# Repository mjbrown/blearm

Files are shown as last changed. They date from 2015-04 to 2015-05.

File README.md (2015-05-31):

# blearm
Open source hardware, firmware, and software for a Bluetooth Low Energy PiHAT.  This PiHAT was used to control a robot arm demonstration for Maker Faire MSP.

1. Firmware includes BGScript and XML files which define the embedded Bluetooth Low Energy device.  
2. Mechanical files include all 3d printed models used to construct the robot arm.  
3. Hardware files include schematics and layout eagle files for the circuit board.  
4. Software includes python scripts used in the development of the hardware.xml settings for PWM.
5. Android includes the modified Bluetooth LE Android application used to control the blearm.

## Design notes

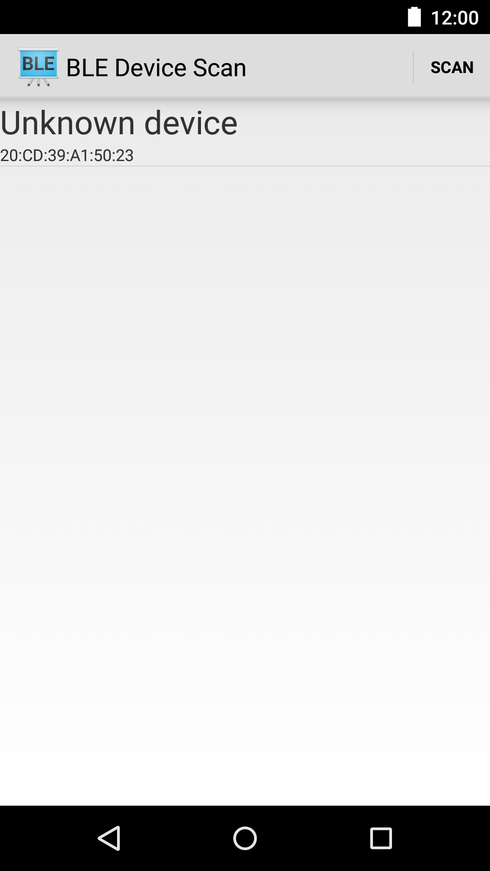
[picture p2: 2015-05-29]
android/screenshots/1-main.png

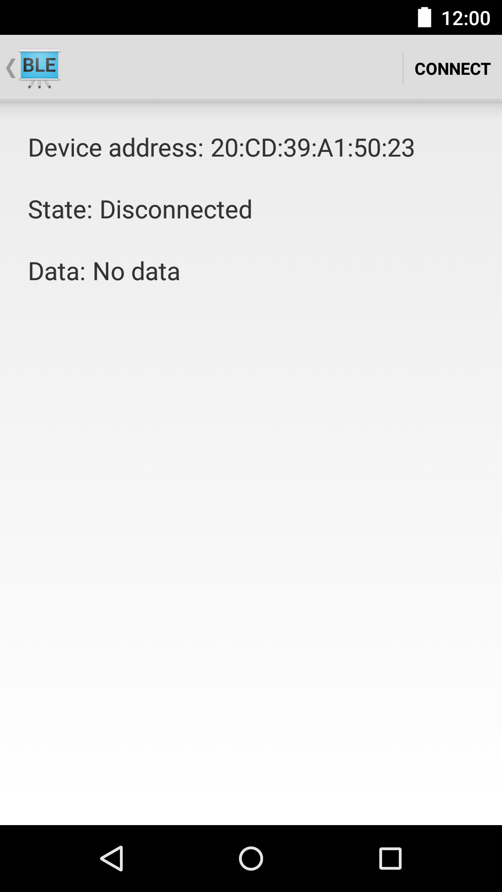
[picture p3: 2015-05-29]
android/screenshots/2-detail.png

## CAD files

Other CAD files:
mechanical/D-gear_wheel.skp
mechanical/D-gear_wheel_7mm.skp
mechanical/D-wheel.skp
mechanical/angle_join.skp
mechanical/arm_platform.skp
mechanical/axle_gear4.skp
mechanical/battery_clip.skp
mechanical/futaba_gear.skp
mechanical/gripper_arm.skp
mechanical/gripper_attach.skp
mechanical/gripper_base.skp
mechanical/gripper_left_claw.skp
mechanical/gripper_right_claw.skp
mechanical/gripper_servo_gear.skp
mechanical/gripper_slave_gear.skp
mechanical/midstop_gear.skp
mechanical/servo_arm.skp
mechanical/servo_arm_raspi.skp
mechanical/servo_horn_gear.skp
mechanical/servo_truck.skp
mechanical/servo_truck_opp.skp
mechanical/track_endstop.skp
mechanical/track_endstop_base.skp
mechanical/track_midstop.skp
mechanical/track_wheel.skp
mechanical/wire_clip.skp

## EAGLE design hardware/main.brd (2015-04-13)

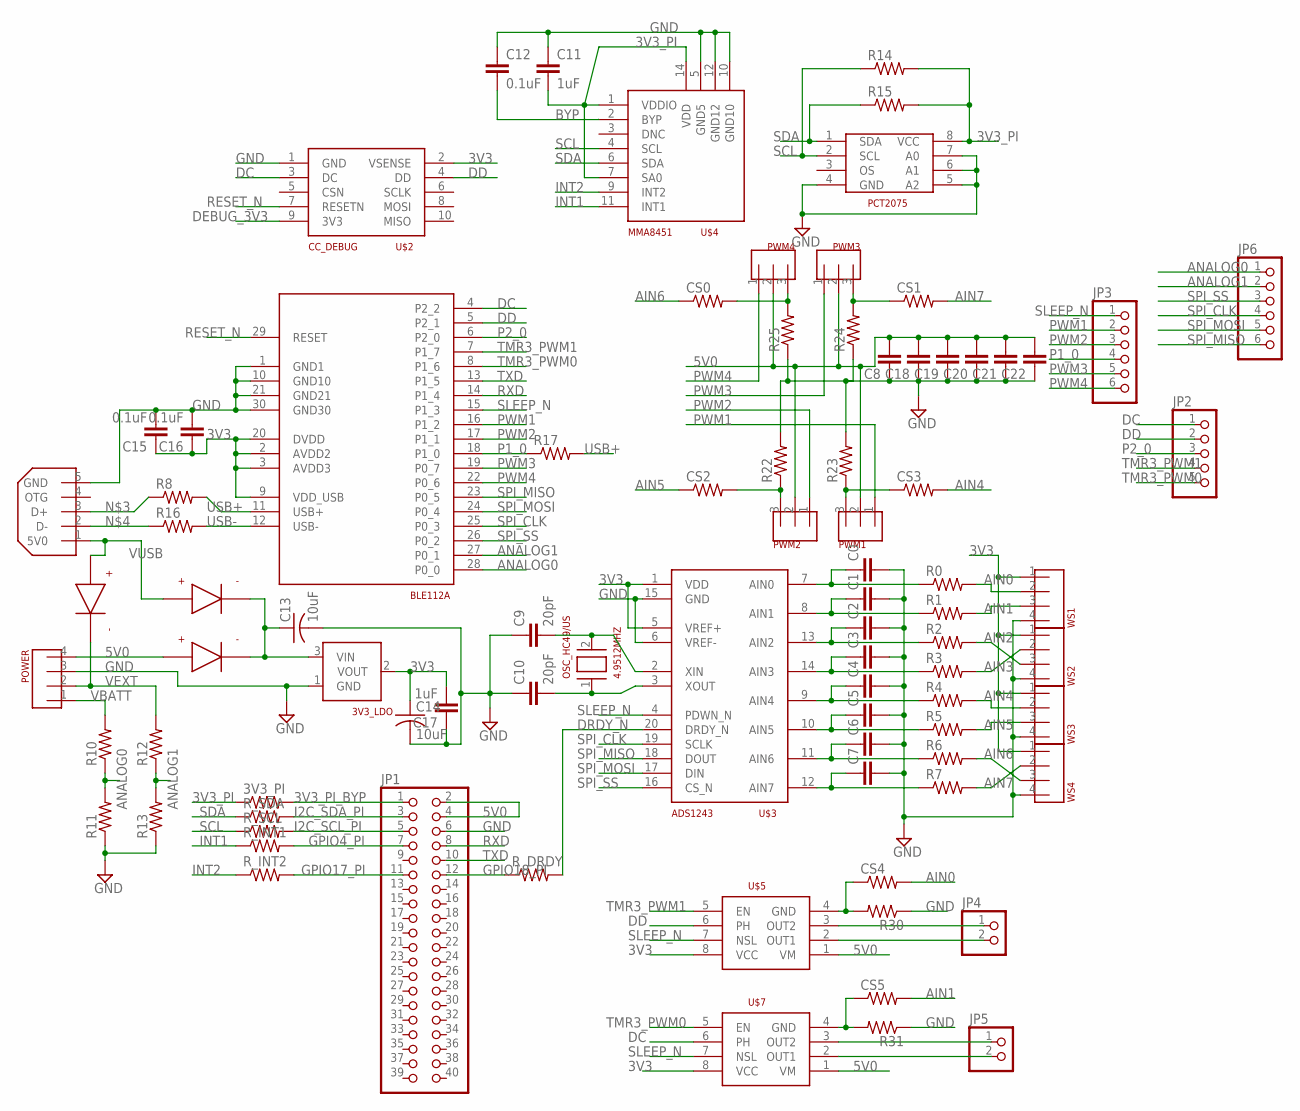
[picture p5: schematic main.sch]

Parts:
3V3_LDO: MCP1700; SOT23
3V3_PI: R-US_R0603; R0603
4.9512MHZ: OSC_HC49/US; HC49UP
BLE112A: BLE112A; BLE112
C0, C1, C2, C3, C4, C5, C6, C7, C8, C18, C19, C20, C21, C22: C-EUC0603; C0603
C9, C10: 20pF; C0603
C11, C17: 1uF; C0603
C12, C15, C16: 0.1uF; C0603
C13, C14: 10uF; C0805
CS0, CS1, CS2, CS3, CS4, CS5: R-US_R0603; R0603
JP1: PINHD-2X20; 2X20
JP2: PINHD-1X5; 1X05
JP3, JP6: PINHD-1X6; 1X06
JP4, JP5: PINHD-1X2; 1X02
PCT2075: PCT2075; SO-08
POWER: HDR_SPOX4
PWM1, PWM2, PWM3, PWM4: HDR_1X3
R0, R1, R2, R3, R4, R5, R6, R7, R8, R10, R11, R12, R13, R14, R15, R16, R17: R-US_R0603; R0603
R22, R23, R24, R25, R30, R31: R-US_R1206; R1206
R_DRDY: R-US_R0603; R0603
R_INT1, R_INT2: R-US_R0603; R0603
R_SCL: R-US_R0603; R0603
R_SDA: R-US_R0603; R0603
U$1, U$11, U$12: SCHOTTKEY_DIODE_1206; DIODE_1206
U$2: CC_DEBUG; HDR_2X5_127MM
U$3: ADS1243; TSSOP20
U$4: MMA8451; QFN16_3X3
U$5, U$7: DRV8838; WSON-8-PAD
U$6: MICRO_USB
WS1, WS2, WS3, WS4: HDR_1X4

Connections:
3V3: 3V3_LDO.2 (VOUT), BLE112A.2 (AVDD2), BLE112A.3 (AVDD3), BLE112A.9 (VDD_USB), BLE112A.20 (DVDD), C14.1, C15.1, C16.1, C17.2, U$2.2 (VSENSE), U$3.1 (VDD), U$3.5 (VREF+), U$5.8 (VCC), U$7.8 (VCC), WS1.1, WS2.1, WS3.1, WS4.1
3V3_PI: 3V3_PI.1, C11.2, PCT2075.8 (VCC), R14.2, R15.2, U$4.1 (VDDIO), U$4.7 (SA0), U$4.14 (VDD)
3V3_PI_BYP: 3V3_PI.2, JP1.1
5V0: C8.2, C18.2, C19.2, C20.2, C21.2, C22.2, JP1.2, JP1.4, POWER.4, PWM1.2, PWM2.2, PWM3.2, PWM4.2, U$5.1 (VM), U$7.1 (VM), U$12.CATHODE+
AIN0: CS4.2, R0.2, WS1.2
AIN1: CS5.2, R1.2, WS1.3
AIN2: R2.2, WS2.3
AIN3: R3.2, WS2.2
AIN4: CS3.2, R4.2, WS3.2
AIN5: CS2.1, R5.2, WS3.3
AIN6: CS0.1, R6.2, WS4.3
AIN7: CS1.2, R7.2, WS4.2
ANALOG0: BLE112A.28 (P0_0), JP6.1, R10.1, R11.2
ANALOG1: BLE112A.27 (P0_1), JP6.2, R12.1, R13.2
BYP: C12.2, U$4.2 (BYP)
DC: BLE112A.4 (P2_2), JP2.1, U$2.3 (DC), U$7.6 (PH)
DD: BLE112A.5 (P2_1), JP2.2, U$2.4 (DD), U$5.6 (PH)
DEBUG_3V3: U$2.9 (3V3)
DRDY_N: R_DRDY.2, U$3.20 (DRDY_N)
GND: 3V3_LDO.1 (GND), BLE112A.1 (GND1), BLE112A.10 (GND10), BLE112A.21 (GND21), BLE112A.30 (GND30), C0.2, C1.2, C2.2, C3.2, C4.2, C5.2, C6.2, C7.2, C8.1, C9.1, C10.1, C11.1, C12.1, C13.2, C14.2, C15.2, C16.2, C17.1, C18.1, C19.1, C20.1, C21.1, C22.1, JP1.6, PCT2075.4 (GND), PCT2075.5 (A2), PCT2075.6 (A1), PCT2075.7 (A0), POWER.3, R11.1, R13.1, R22.2, R23.2, R24.1, R25.1, R30.1, R31.1, U$2.1 (GND), U$3.6 (VREF-), U$3.15 (GND), U$4.5 (GND5), U$4.10 (GND10), U$4.12 (GND12), U$6.5 (GND), WS1.4, WS2.4, WS3.4, WS4.4
GPIO4_PI: JP1.7, R_INT1.2
GPIO17_PI: JP1.11, R_INT2.2
GPIO18_PI: JP1.12, R_DRDY.1
I2C_SCL_PI: JP1.5, R_SCL.2
I2C_SDA_PI: JP1.3, R_SDA.2
INT1: R_INT1.1, U$4.11 (INT1)
INT2: R_INT2.1, U$4.9 (INT2)
unnamed: C0.1, R0.1, U$3.7 (AIN0)
unnamed: C1.1, R1.1, U$3.8 (AIN1)
unnamed: R8.1, U$6.3 (D+)
unnamed: R16.1, U$6.2 (D-)
unnamed: 3V3_LDO.3 (VIN), C13.1, U$11.ANODE-, U$12.ANODE-
unnamed: C2.1, R2.1, U$3.13 (AIN2)
unnamed: C3.1, R3.1, U$3.14 (AIN3)
unnamed: C4.1, R4.1, U$3.9 (AIN4)
unnamed: C5.1, R5.1, U$3.10 (AIN5)
unnamed: C6.1, R6.1, U$3.11 (AIN6)
unnamed: C7.1, R7.1, U$3.12 (AIN7)
unnamed: JP4.1, U$5.3 (OUT2)
unnamed: CS2.2, PWM2.3, R22.1
unnamed: CS3.1, PWM1.3, R23.1
unnamed: CS0.2, PWM4.3, R25.2
unnamed: CS1.1, PWM3.3, R24.2
unnamed: JP4.2, U$5.2 (OUT1)
unnamed: JP5.1, U$7.3 (OUT2)
unnamed: JP5.2, U$7.2 (OUT1)
unnamed: 4.9512MHZ.2, C9.2, U$3.2 (XIN)
unnamed: 4.9512MHZ.1, C10.2, U$3.3 (XOUT)
unnamed: CS4.1, R30.2, U$5.4 (GND)
unnamed: CS5.1, R31.2, U$7.4 (GND)
P1_0: BLE112A.18 (P1_0), JP3.4, R17.1
P2_0: BLE112A.6 (P2_0), JP2.3
PWM1: BLE112A.16 (P1_2), JP3.2, PWM1.1
PWM2: BLE112A.17 (P1_1), JP3.3, PWM2.1
PWM3: BLE112A.19 (P0_7), JP3.5, PWM3.1
PWM4: BLE112A.22 (P0_6), JP3.6, PWM4.1
RESET_N: BLE112A.29 (RESET), U$2.7 (RESETN)
RXD: BLE112A.14 (P1_4), JP1.8
SCL: PCT2075.2 (SCL), R14.1, R_SCL.1, U$4.4 (SCL)
SDA: PCT2075.1 (SDA), R15.1, R_SDA.1, U$4.6 (SDA)
SLEEP_N: BLE112A.15 (P1_3), JP3.1, U$3.4 (PDWN_N), U$5.7 (NSL), U$7.7 (NSL)
SPI_CLK: BLE112A.25 (P0_3), JP6.4, U$3.19 (SCLK)
SPI_MISO: BLE112A.23 (P0_5), JP6.6, U$3.18 (DOUT)
SPI_MOSI: BLE112A.24 (P0_4), JP6.5, U$3.17 (DIN)
SPI_SS: BLE112A.26 (P0_2), JP6.3, U$3.16 (CS_N)
TMR3_PWM0: BLE112A.8 (P1_6), JP2.5, U$7.5 (EN)
TMR3_PWM1: BLE112A.7 (P1_7), JP2.4, U$5.5 (EN)
TXD: BLE112A.13 (P1_5), JP1.10
USB+: BLE112A.11 (USB+), R8.2, R17.2
USB-: BLE112A.12 (USB-), R16.2
VBATT: POWER.1, R10.2
VEXT: POWER.2, R12.2, U$1.ANODE-
VUSB: U$1.CATHODE+, U$6.1 (5V0), U$11.CATHODE+

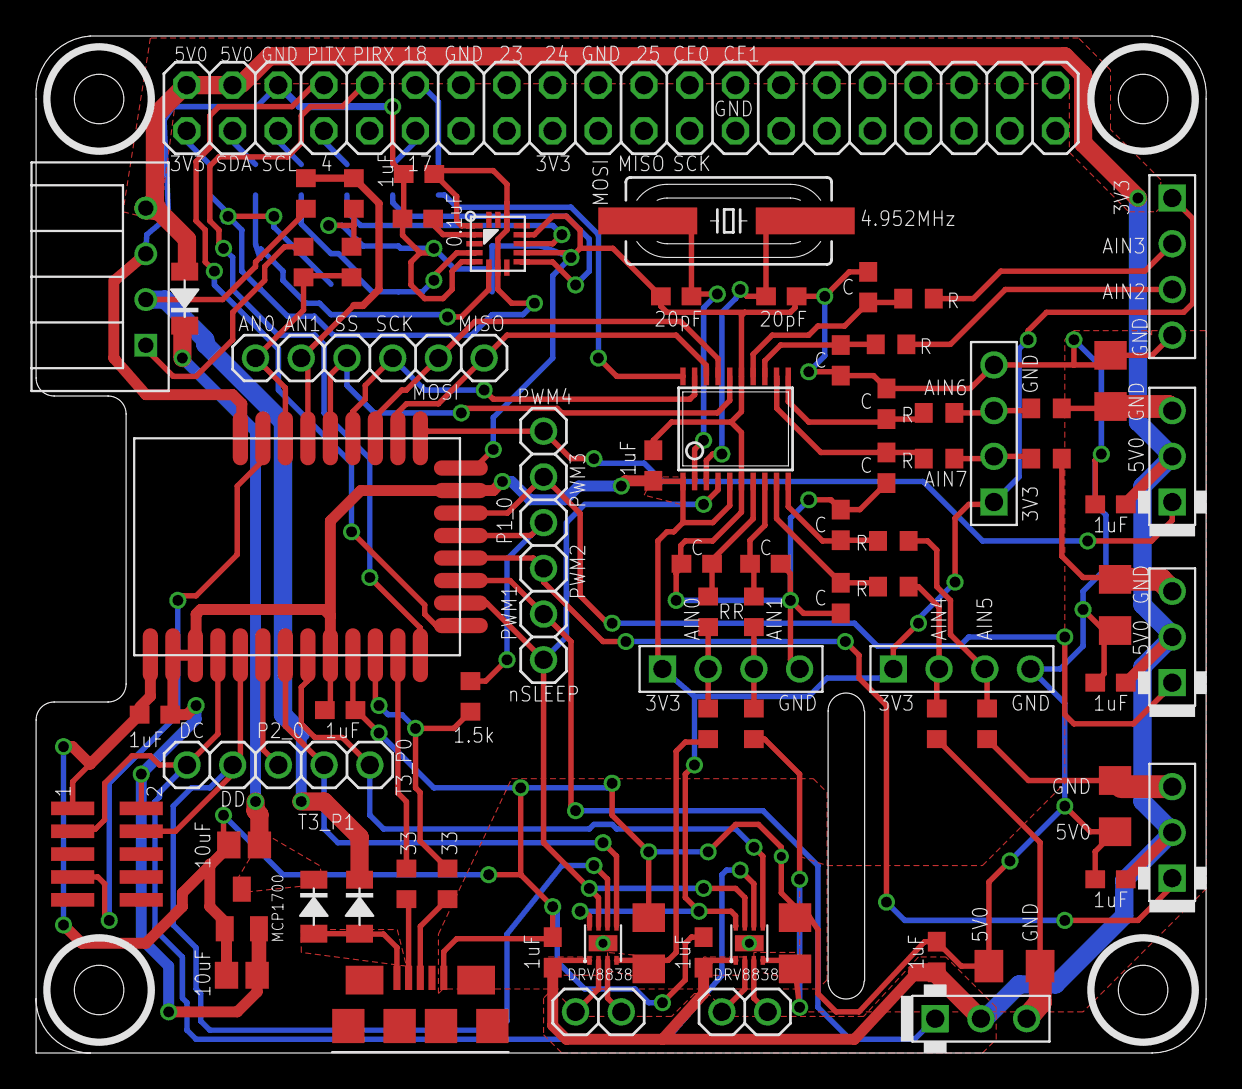
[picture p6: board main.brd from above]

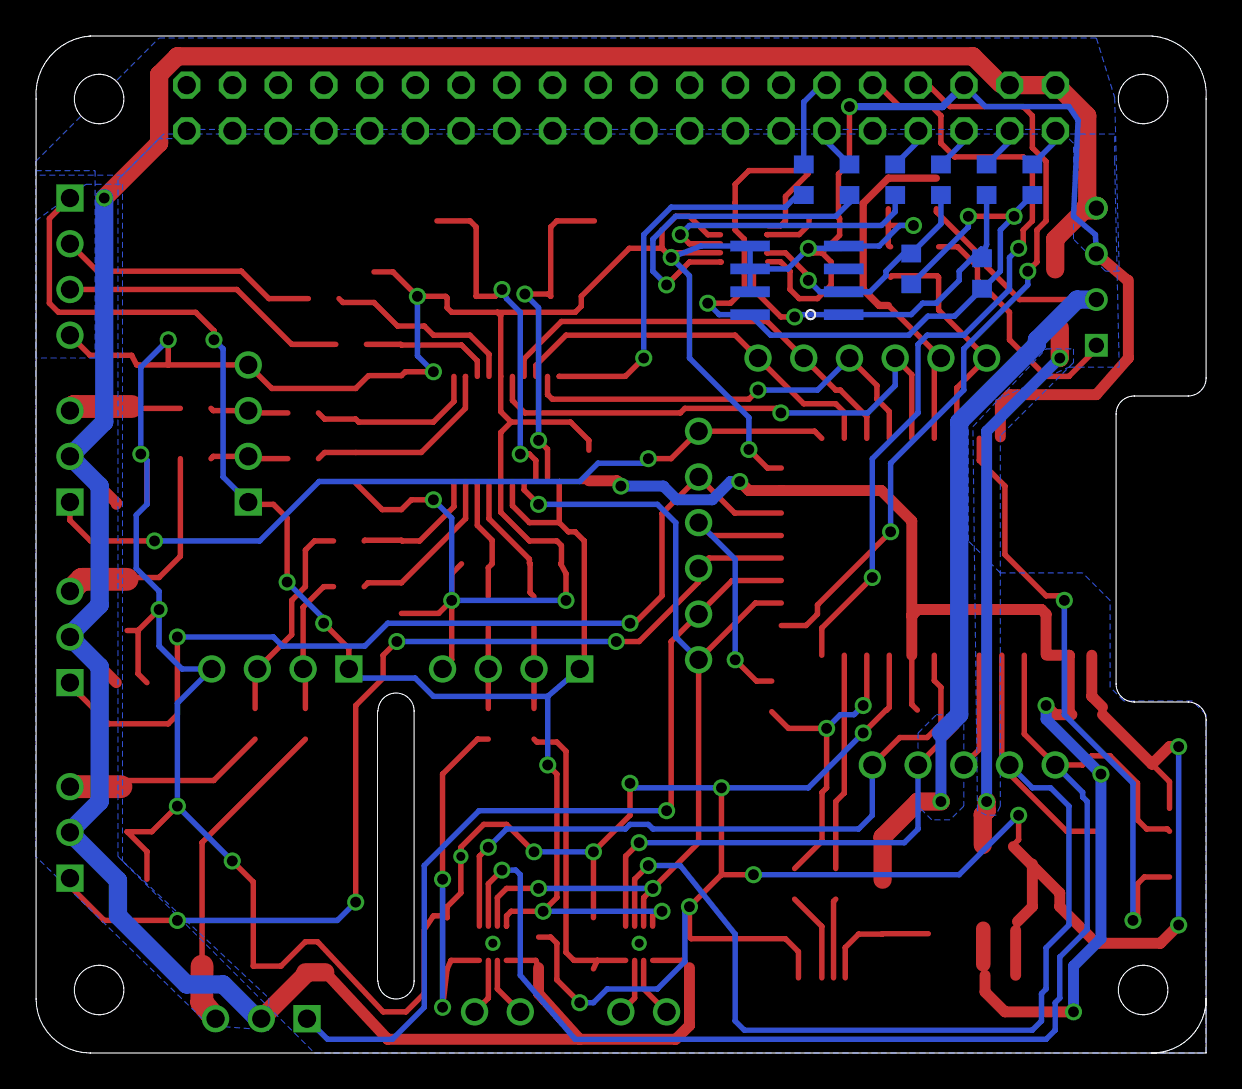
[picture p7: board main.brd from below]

Board: 2 copper layers, 65.0 x 56.5 mm, 86 parts (9 on the bottom side), 72 nets.

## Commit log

2015-03-20 Hardware and firmware for revision 1.
    [main.brd, main.sch]
2015-03-20 Add temperature sensor read over I2C.
2015-04-13 Hardware revision 2, as ordered.
    [main.brd, main.sch]
2015-05-29 Initial commit of all models for 3d printing.
    [D-gear_wheel.skp, D-gear_wheel_7mm.skp, D-wheel.skp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]
2015-05-29 BGScript for controlling all six PWMs via attribute writes.
2015-05-31 Android user interface for controlling robot arm shown at Maker Faire MSP.
